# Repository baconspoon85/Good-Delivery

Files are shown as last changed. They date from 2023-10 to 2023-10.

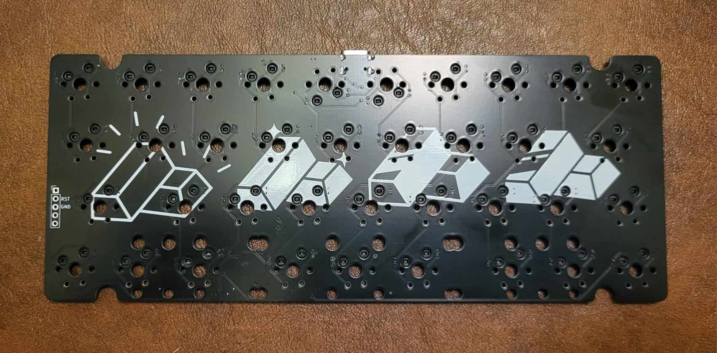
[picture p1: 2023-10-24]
good-delivery-standard-stagger-pcb-front.jpg

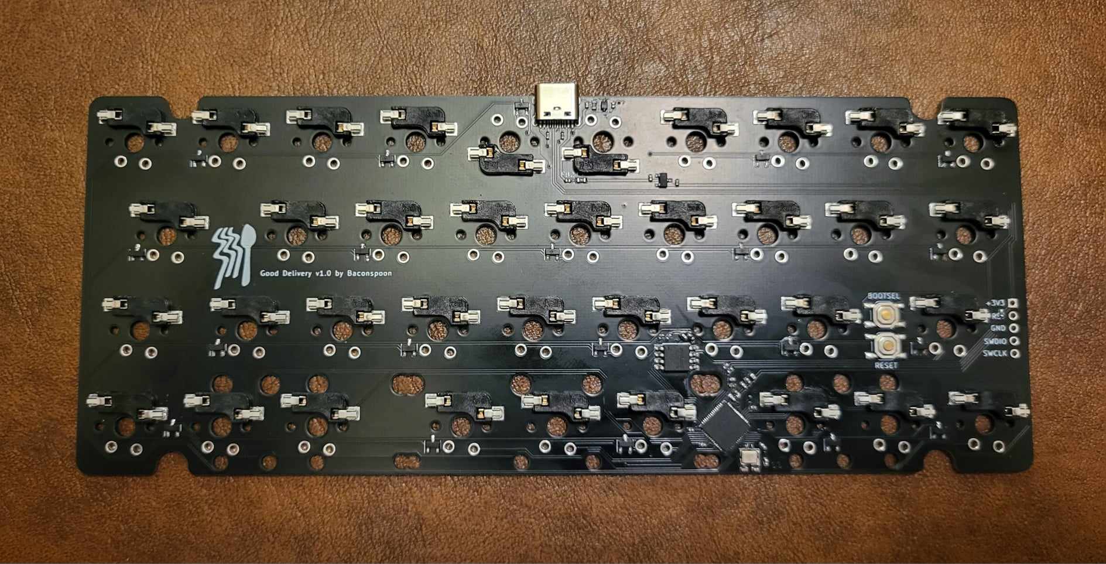
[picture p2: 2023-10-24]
good-delivery-standard-stagger-pcb-back.jpg

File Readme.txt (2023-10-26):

Good Delivery is a pair of 10x4u PCBs featuring:
-Standard stagger layout
	Proto built and tested. Fully functional.
-Alpha stagger layout
	Proto pending.
-RP2040 MCU
-Hotswap MX support (w/ option to solder the corner switches for better o-ring stability with 3-pin switches)
-Solder Alps support
-Physical compatibility with Acai by CBKBD
	-Centered USB
	-Gummy O-ring mount

good-delivery-standard-stagger-pcb-front
good-delivery-standard-stagger-pcb-back
good-delivery-kle
matrix and pinout

Vial firmware supporting both the standard row stagger and alpha stagger is complete, courtesy of Flamwenco! Big thank you. Check his Cutiepie repo, also forked on my page.

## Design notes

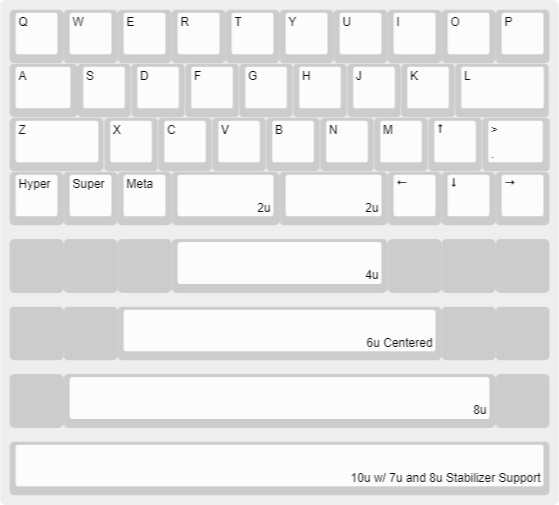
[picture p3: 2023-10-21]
good-delivery-layout.png

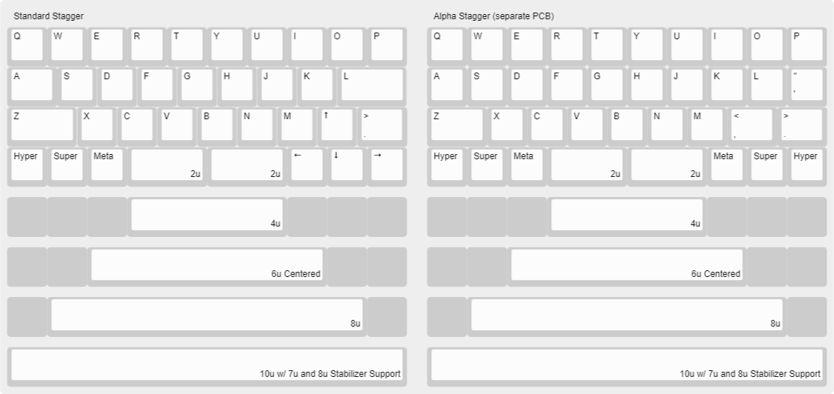
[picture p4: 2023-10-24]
good-delivery-kle.png

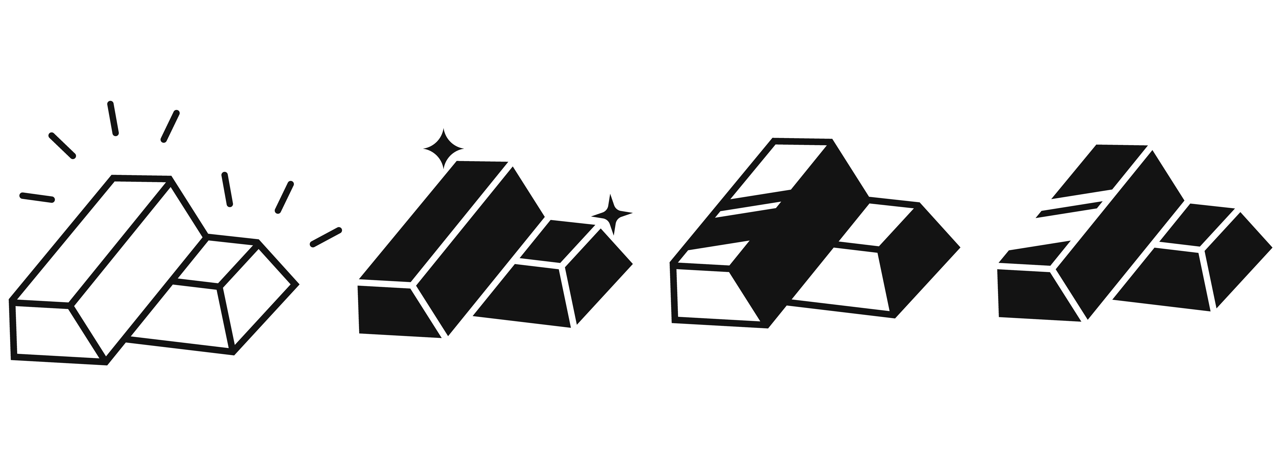
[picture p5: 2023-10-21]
good-delivery-bars-silkscreen.jpeg

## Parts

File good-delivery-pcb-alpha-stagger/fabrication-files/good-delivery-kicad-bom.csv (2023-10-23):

Comment | Designator | Footprint | JLCPCB Part#
1uF | C_1V-Decoup1 | C_0402_1005Metric | C52923
100nF | C_1V-Decoup2 | C_0402_1005Metric | C2655418
100nF | C_1V-Decoup3 | C_0402_1005Metric | C2655418
10uF | C_3V-Decoup1 | C_0402_1005Metric | C15525
1uF | C_3V-Decoup2 | C_0402_1005Metric | C52923
100nF | C_3V-Decoup3 | C_0402_1005Metric | C2655418
100nF | C_3V-Decoup4 | C_0402_1005Metric | C2655418
100nF | C_3V-Decoup5 | C_0402_1005Metric | C2655418
100nF | C_3V-Decoup6 | C_0402_1005Metric | C2655418
100nF | C_3V-Decoup7 | C_0402_1005Metric | C2655418
100nF | C_3V-Decoup8 | C_0402_1005Metric | C2655418
100nF | C_3V-Decoup9 | C_0402_1005Metric | C2655418
22pF | C_Crystal1 | C_0402_1005Metric | C1555
22pF | C_Crystal2 | C_0402_1005Metric | C1555
100nF | C_Flash1 | C_0402_1005Metric | C2655418
1uF | C_LD1 | C_0402_1005Metric | C52923
1uF | C_LD2 | C_0402_1005Metric | C52923
100nF | C1 | C_0402_1005Metric | C2655418
BAV70 | D1 | SOT-23 | C154830
BAV70 | D10 | SOT-23 | C154830
BAV70 | D11 | SOT-23 | C154830
BAV70 | D12 | SOT-23 | C154830
BAV70 | D13 | SOT-23 | C154830
BAV70 | D14 | SOT-23 | C154830
BAV70 | D15 | SOT-23 | C154830
BAV70 | D16 | SOT-23 | C154830
BAV70 | D17 | SOT-23 | C154830
BAV70 | D18 | SOT-23 | C154830
BAV70 | D19 | SOT-23 | C154830
BAV70 | D2 | SOT-23 | C154830
BAV70 | D20 | SOT-23 | C154830
BSD3C051V | D21 | D_SOD-323 | C151996
BAV70 | D3 | SOT-23 | C154830
BAV70 | D4 | SOT-23 | C154830
BAV70 | D5 | SOT-23 | C154830
BAV70 | D6 | SOT-23 | C154830
BAV70 | D7 | SOT-23 | C154830
BAV70 | D8 | SOT-23 | C154830
BAV70 | D9 | SOT-23 | C154830
0603L075SLYR | F1 | Fuse_0603_1608Metric | C207016
BLM15PX121SN1D | FB1 | L_0402_1005Metric | C88970
BLM15PX121SN1D | FB2 | L_0402_1005Metric | C88970
USB_C_Receptacle_USB2.0 | J3 | USB_C_Receptacle_HRO_TYPE-C-31-M-12 | C165948
1k ohm | R_Crystal1 | R_0402_1005Metric | C279987
27 ohm | R_DATA1 | R_0402_1005Metric | C25100
27 ohm | R_DATA2 | R_0402_1005Metric | C25100
5.1k ohm | R_Flash1 | R_0402_1005Metric | C103086
5.1k ohm | R_Flash2 | R_0402_1005Metric | C103086
1k ohm | R_Flash3 | R_0402_1005Metric | C279987
5.1k ohm | R_RST1 | R_0402_1005Metric | C103086
1M ohm | R1 | R_0603_1608Metric | C3016422
5.1k ohm | R2 | R_0402_1005Metric | C103086
5.1k ohm | R3 | R_0402_1005Metric | C103086
RESET | SW1 | SW_SPST_TL3342 | C318884
BOOTSEL | SW2 | SW_SPST_TL3342 | C318884
RP2040 | U1 | RP2040-QFN-56 | C2040
W25Q128JVS | U2 | SOIC-8_5.23x5.23mm_P1.27mm | C2613930
XC6206P332MR | U3 | SOT-23 | C5446
12MHz | Y1 | Crystal_SMD_3225-4Pin_3.2x2.5mm | C9002

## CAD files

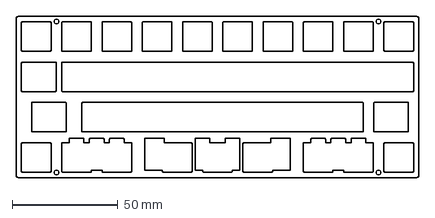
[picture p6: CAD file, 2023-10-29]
good-delivery-plate/good-delivery-dual-stagger-plate.dxf
190.5 x 76.2 mm

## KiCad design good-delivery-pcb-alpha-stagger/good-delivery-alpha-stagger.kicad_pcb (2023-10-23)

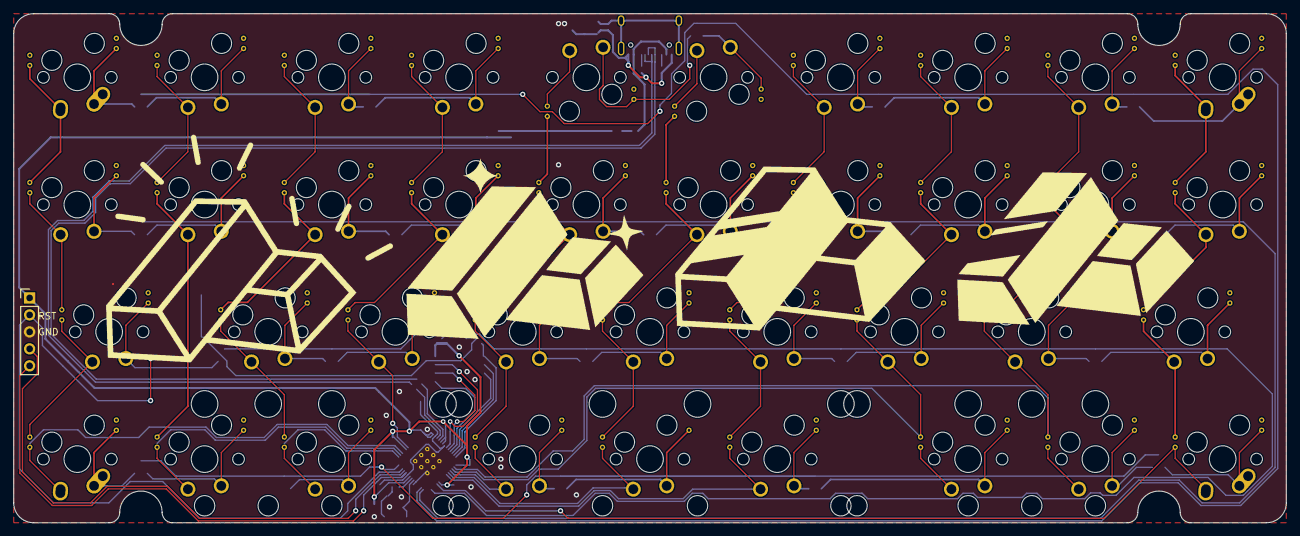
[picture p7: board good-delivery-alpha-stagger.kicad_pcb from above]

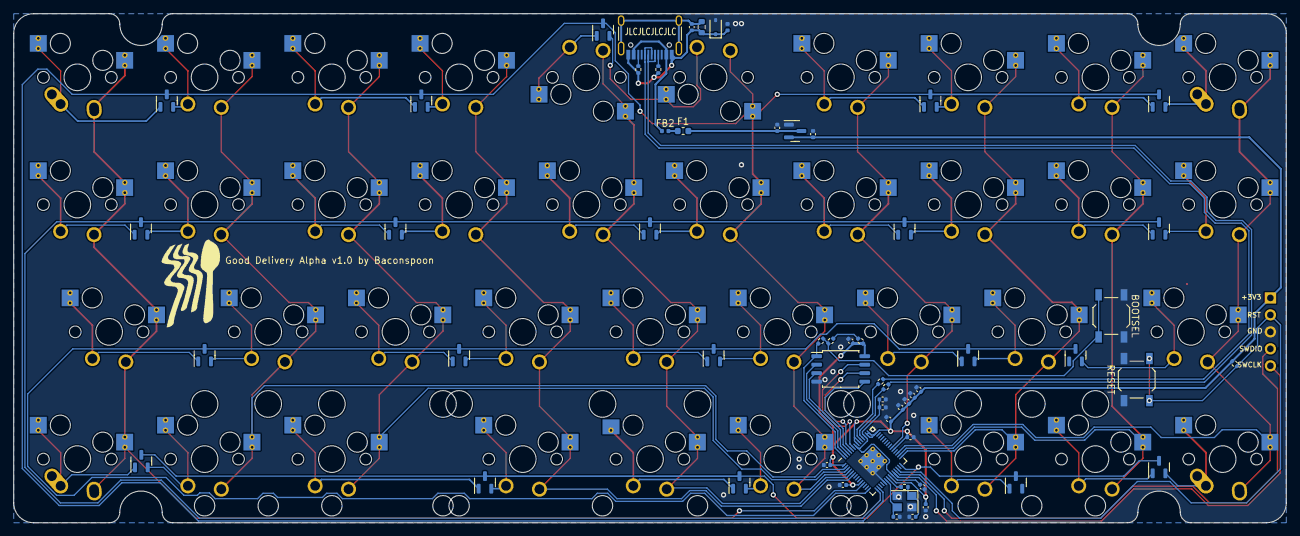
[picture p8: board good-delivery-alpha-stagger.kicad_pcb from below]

Board: 2 copper layers, 190.5 x 76.2 mm, 100 parts (60 on the bottom side), 80 nets.

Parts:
C1: 100nF; C_0402_1005Metric
C_1V-Decoup1, C_3V-Decoup2: 1u; C_0402_1005Metric
C_1V-Decoup2, C_1V-Decoup3, C_3V-Decoup3, C_3V-Decoup4, C_3V-Decoup5, C_3V-Decoup6, C_3V-Decoup7, C_3V-Decoup8, C_3V-Decoup9: 100n; C_0402_1005Metric
C_3V-Decoup1: 10u; C_0402_1005Metric
C_Crystal1, C_Crystal2: 22p; C_0402_1005Metric
C_Flash1: 100n; C_0402_1005Metric
C_LD1, C_LD2: 1u; C_0402_1005Metric
D1, D2, D3, D4, D5, D6, D7, D8, D9, D10, D11, D12, D13, D14, D15, D16, D17, D18, D19, D20: BAV70; SOT-23
D21: BSD3C051V; D_SOD-323
F1: 0603L075SLYR; Fuse_0603_1608Metric
FB1, FB2: BLM15PX121SN1D; L_0402_1005Metric
G1: Logo_Open_Hardware_Small; good-delivery-bars-silkscreen
G2: Logo_Open_Hardware_Small; baconspoon-logo-15mm
J2: SWD; PinHeader_1x05_P2.54mm_Vertical
J3: USB_C_Receptacle_USB2.0; USB_C_Receptacle_HRO_TYPE-C-31-M-12
MX1, MX4, MX5, MX6, MX7, MX8, MX9, MX10, MX11, MX12, MX13, MX14, MX15, MX16, MX17, MX18, MX20, MX21, MX22, MX24, MX25, MX26, MX28, MX29, MX30, MX31, MX32, MX33, MX34, MX35, MX38: MX-NoLED; 1U-MX-Hotswap-Alps-Solder-PadSwapped
MX2, MX36: MX-NoLED; 1U-MX-Hotswap-Alps-Solder
MX3, MX37: MX-NoLED; 1.5U-MX-Hotswap-Alps-Solder
MX19, MX27: MX-NoLED; 2U-MX-Hotswap-Alps-Solder-PadSwapped-ReversedStabilizers
MX23: MX-NoLED; 4,6,7,8,10u-MX-Hotswap-Alps-Solder-PadSwapped-ReversedStabi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
R1: 1M; R_0603_1608Metric
R2, R3: 5k1; R_0402_1005Metric
R_Crystal1: 1k; R_0402_1005Metric
R_DATA1, R_DATA2: 27; R_0402_1005Metric
R_Flash1, R_Flash2: 5k1; R_0402_1005Metric
R_Flash3: 1k; R_0402_1005Metric
R_RST1: 5k1; R_0402_1005Metric
SW1: RESET; SW_SPST_TL3342
SW2: BOOTSEL; SW_SPST_TL3342
U1: RP2040; RP2040-QFN-56
U2: W25Q128JVS; SOIC-8_5.23x5.23mm_P1.27mm
U3: XC6206P332MR; SOT-23
Y1: 12MHz; Crystal_SMD_3225-4Pin_3.2x2.5mm

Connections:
+1V1: C_1V-Decoup1.1, C_1V-Decoup2.1, C_1V-Decoup3.1, U1.23 (DVDD), U1.45 (VREG_VOUT), U1.50 (DVDD)
+3V3: C_3V-Decoup1.1, C_3V-Decoup2.1, C_3V-Decoup3.1, C_3V-Decoup4.1, C_3V-Decoup5.1, C_3V-Decoup6.1, C_3V-Decoup7.1, C_3V-Decoup8.1, C_3V-Decoup9.1, C_Flash1.1, C_LD2.1, J2.1, R_Flash1.1, R_RST1.1, U1.1 (IOVDD), U1.10 (IOVDD), U1.22 (IOVDD), U1.33 (IOVDD), U1.42 (IOVDD), U1.43 (ADC_AVDD), U1.44 (VREG_IN), U1.48 (USB_VDD), U1.49 (IOVDD), U2.8 (VCC), U3.2 (VO)
+5V: C_LD1.1, F1.2, U3.3 (VI)
COL 0: MX1.1 (COL), MX2.1 (COL), MX3.1 (COL), MX4.1 (COL), U1.31 (GPIO20)
COL 1: MX6.1 (COL), MX7.1 (COL), MX8.1 (COL), U1.30 (GPIO19)
COL 2: MX9.1 (COL), MX10.1 (COL), MX11.1 (COL), MX12.1 (COL), U1.29 (GPIO18)
COL 3: MX13.1 (COL), MX14.1 (COL), MX15.1 (COL), U1.34 (GPIO22)
COL 4: MX16.1 (COL), MX17.1 (COL), MX18.1 (COL), MX19.1 (COL), U1.4 (GPIO2)
COL 5: MX20.1 (COL), MX21.1 (COL), MX22.1 (COL), MX23.1 (COL), U1.5 (GPIO3)
COL 6: MX24.1 (COL), MX25.1 (COL), MX26.1 (COL), MX27.1 (COL), U1.6 (GPIO4)
COL 7: MX28.1 (COL), MX29.1 (COL), MX30.1 (COL), MX31.1 (COL), U1.3 (GPIO1)
COL 8: MX5.1 (COL), MX32.1 (COL), MX33.1 (COL), MX34.1 (COL), U1.2 (GPIO0)
COL 9: MX35.1 (COL), MX36.1 (COL), MX37.1 (COL), MX38.1 (COL), U1.11 (GPIO8)
CS: R_Flash3.2, U1.56 (QSPI_SS), U2.1 (~CS)
D+: J3.A6 (D+), J3.B6 (D+), R_DATA1.1
D-: J3.A7 (D-), J3.B7 (D-), R_DATA2.1
Earth: C1.1, J3.S1 (SHIELD), R1.1
GND: C_1V-Decoup1.2, C_1V-Decoup2.2, C_1V-Decoup3.2, C_3V-Decoup1.2, C_3V-Decoup2.2, C_3V-Decoup3.2, C_3V-Decoup4.2, C_3V-Decoup5.2, C_3V-Decoup6.2, C_3V-Decoup7.2, C_3V-Decoup8.2, C_3V-Decoup9.2, C_Crystal1.1, C_Crystal2.1, C_Flash1.2, C_LD1.2, C_LD2.2, D21.2 (A2), FB1.2, J2.3, SW1.1, SW2.1, U1.19 (TESTEN), U1.57 (GND), U2.4 (GND), U3.1 (GND), Y1.2, Y1.4
GNDPWR: C1.2, D21.1 (A1), FB1.1, J3.A1 (GND), J3.A12 (GND), J3.B1 (GND), J3.B12 (GND), R1.2, R2.2, R3.2
unnamed: C_Crystal2.2, R_Crystal1.1, Y1.1
unnamed: F1.1, FB2.2
unnamed: J3.A5 (CC1), R2.1
unnamed: J3.B5 (CC2), R3.1
unnamed: D1.2 (A), MX1.2 (ROW)
unnamed: D2.2 (A), MX2.2 (ROW)
unnamed: D3.2 (A), MX3.2 (ROW)
unnamed: D4.2 (A), MX4.2 (ROW)
unnamed: D18.2 (A), MX5.2 (ROW)
unnamed: D1.1 (A), MX6.2 (ROW)
unnamed: D2.1 (A), MX7.2 (ROW)
unnamed: D4.1 (A), MX8.2 (ROW)
unnamed: D5.2 (A), MX9.2 (ROW)
unnamed: D6.2 (A), MX10.2 (ROW)
unnamed: D7.2 (A), MX11.2 (ROW)
unnamed: D8.1 (A), MX12.2 (ROW)
unnamed: D5.1 (A), MX13.2 (ROW)
unnamed: D6.1 (A), MX14.2 (ROW)
unnamed: D7.1 (A), MX15.2 (ROW)
unnamed: D9.2 (A), MX16.2 (ROW)
unnamed: D10.2 (A), MX17.2 (ROW)
unnamed: D11.2 (A), MX18.2 (ROW)
unnamed: D12.2 (A), MX19.2 (ROW)
unnamed: D9.1 (A), MX20.2 (ROW)
unnamed: D10.1 (A), MX21.2 (ROW)
unnamed: D11.1 (A), MX22.2 (ROW)
unnamed: D12.1 (A), MX23.2 (ROW)
unnamed: D13.2 (A), MX24.2 (ROW)
unnamed: D14.2 (A), MX25.2 (ROW)
unnamed: D15.2 (A), MX26.2 (ROW)
unnamed: D16.2 (A), MX27.2 (ROW)
unnamed: D13.1 (A), MX28.2 (ROW)
unnamed: D14.1 (A), MX29.2 (ROW)
unnamed: D15.1 (A), MX30.2 (ROW)
unnamed: D16.1 (A), MX31.2 (ROW)
unnamed: D17.2 (A), MX32.2 (ROW)
unnamed: D19.2 (A), MX33.2 (ROW)
unnamed: D20.2 (A), MX34.2 (ROW)
unnamed: D17.1 (A), MX35.2 (ROW)
unnamed: D18.1 (A), MX36.2 (ROW)
unnamed: D19.1 (A), MX37.2 (ROW)
unnamed: D20.1 (A), MX38.2 (ROW)
unnamed: R_Flash1.2, R_Flash2.1
unnamed: R_Flash2.2, R_Flash3.1, SW2.2
unnamed: R_DATA2.2, U1.46 (USB_DM)
unnamed: R_DATA1.2, U1.47 (USB_DP)
QSPI_CLK: U1.52 (QSPI_SCLK), U2.6 (CLK)
RESET: J2.2, R_RST1.2, SW1.2, U1.26 (RUN)
ROW 0: D1.3 (K), D5.3 (K), D9.3 (K), D13.3 (K), D17.3 (K), U1.16 (GPIO13)
ROW 1: D2.3 (K), D6.3 (K), D10.3 (K), D14.3 (K), D18.3 (K), U1.15 (GPIO12)
ROW 2: D3.3 (K), D7.3 (K), D11.3 (K), D15.3 (K), D19.3 (K), U1.14 (GPIO11)
ROW 3: D4.3 (K), D8.3 (K), D12.3 (K), D16.3 (K), D20.3 (K), U1.28 (GPIO17)
SD0: U1.53 (QSPI_SD0), U2.5 (DI(IO0))
SD1: U1.55 (QSPI_SD1), U2.2 (DO(IO1))
SD2: U1.54 (QSPI_SD2), U2.3 (IO2)
SD3: U1.51 (QSPI_SD3), U2.7 (IO3)
SWCLK: J2.5, U1.24 (SWCLK)
SWDIO: J2.4, U1.25 (SWD)
VBUS: FB2.1, J3.A4 (VBUS), J3.A9 (VBUS), J3.B4 (VBUS), J3.B9 (VBUS)
XTAL_IN: C_Crystal1.2, U1.20 (XIN), Y1.3
XTAL_OUT: R_Crystal1.2, U1.21 (XOUT)

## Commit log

2023-10-22 Added option to solder MX corner switches for improved gummy o-ring support with 3-pin switches.
    [good-delivery.kicad_pcb]
2023-10-23 Add alpha stagger PCB
    [good-delivery-alpha-stagger-B_Cu.gbl, good-delivery-alpha-stagger-B_Mask.gbs, good-delivery-alpha-stagger-B_Paste.gbp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]
2023-10-24 Update Readme.txt
    Update to PCB features and development status.
2023-10-24 Add proto pcb images and kle image
2023-10-29 add dual stagger plate outline and fr4 gerbers
    [dual-stagger-good-delivery-plate-B_Cu.gbl, dual-stagger-good-delivery-plate-B_Mask.gbs, dual-stagger-good-delivery-plate-B_Paste.gbp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]
